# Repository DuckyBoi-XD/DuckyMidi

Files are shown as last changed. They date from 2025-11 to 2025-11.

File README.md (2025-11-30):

# DuckyMidi
The DuckyMidi is a Midi keyboard made from the mini midi magic guide which has a theme of Ducks
Screenshot 2025-11-22 at 9 00 30 PM

## Features

The DuckyMidi has all these features:

- 2 octaves for wide range of sounds
- LCD display for menu display
- 2 rotary knobs for menu/Midi control
- 12 macro keys
- Orpheus Pico microcontroller
- Gateron Pro black switches to feel like a piano key
- Manual on/off switch

## Inspiration

The DuckyMidi was created using the help of the guide from the mini midi magic and was created for many reasons. I'm experienced in music and when I saw the guide for the midi made me intreseted in making a Midi keyboard myself. This was also a great time to revise/practise my PCB designing and CAD modeling.

## Construction
The DuckyMidi is created with a custom PCB and case.

### PCB
The DuckyMidi's PCB:

Screenshot 2025-11-25 at 2 12 49 PM
Screenshot 2025-11-30 at 7 53 48 PM

### Case

The DuckyMidi's Case:

Screenshot 2025-11-30 at 7 02 26 PM
Screenshot 2025-11-30 at 7 53 29 PM
Screenshot 2025-11-30 at 7 04 42 PM

## BOM

| Component | Description | Quantity | Base Cost | Extra Costs | Link |
|---|---|---|---|---|---|
| MCU | Raspberry Pi Pico Board RP2040 | 1 | $3.03 | (*GST*) | https://www.aliexpress.com/item/1005006087823796.html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 |
| Rotary Encoder | Rotary Encoder EC11 w Push Button 5px | 1 | $2.78 | (*GST*) | https://www.aliexpress.com/item/1005005983134515.html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 |
| Rotary Encoder Knob | Aluminum alloy knob cap x2 | 1 | $2.70 | $3.58 +(*GST*)| https://www.aliexpress.com/item/1005006912587864.html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 |
| Switches Piano | Outemu Switch Mechanical Keyboard Switch Black 70 pcs | 1 | $9.19 | (*GST*) | https://www.aliexpress.com/item/1005002378701948.html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 |
| Keycaps White | 10pcs DSA Keycap Set PBT Blank Keycaps 1.5U | 2 | $7.50 | (*GST*) | https://www.aliexpress.com/item/1005009077100804.html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 |
| Keycaps Black | Customized PBT Blank Keycaps DSA 1.25U 10 pcs | 1 | $3.77 | (*GST*) | https://www.aliexpress.com/item/1005006080902747.html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 |
| Keycaps Macro | YMDK MOA Profile 1u Keycaps Dark Blue 25pcs | 1 | $5.77 | (*GST*) | https://www.aliexpress.com/item/1005008795444732.html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,scm-url:1007.40196.439370.0,pvid:3c3f9d66-ba11-4bbf-9a26-8683f9403fb6,tpp_buckets:668%232846%238108%231977&pdp_ext_f=%7B%22order%22%3A%22161%22%2C%22eval%22%3A%221%22%2C%22sceneId%22%3A%2230050%22%2C%22fromPage%22%3A%22recommend%22%7D&pdp_npi=6%40dis%21USD%213.09%212.39%21%21%213.09%212.39%21%402101c44f17631625120246447ec4f0%2112000046697462934%21rec%21NZ%216394433987%21XZ%211%210%21n_tag%3A-29911%3Bd%3A53947009%3Bm03_new_user%3A-29895&utparam-url=scene%3ApcDetailTopMoreOtherSeller%7Cquery_from%3A%7Cx_object_id%3A1005008795444732%7C_p_origin_prod%3A |
| On Off Switch | Push Button Switch 21x15mm SPST 2Pin 6A 250V 5pcs | 1 | $1.97 | (*GST*) | https://www.aliexpress.com/item/1005007945027854.html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 |
| Diodes | 1N4148 DO-35 100pcs | 1 | $2.51 | (*GST*) | https://www.aliexpress.com/item/1005009896621714.html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 |
| Pin Header | Pin Header 2.0MM/2.54MM Pitch Row Female/Male, Single Row 1x40P | 1 | $3.24 | (*GST*) | https://www.aliexpress.com/item/4001122376295.html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 |
| DAC | PCM5100APWR 5pcs | 1 | $2.13 | (*GST*) | https://www.aliexpress.com/item/1005008173380058.html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 |
| LCD/SD Card port | LCD Module Display | 1 | $3.30 | $3.87 +(*GST*)| https://www.aliexpress.com/item/1005003633248802.html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 |
| Jumper Wires | Dupont Line Female To Female | 1 | $2.87 | (*GST*) | https://www.aliexpress.com/item/1005006994502819.html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 |
| Heat insert | Brass Copper Embed Insert Nut 50pc M3 (OD 4.2mm) 4mm | 1 | $2.43 | (*GST*) | https://www.aliexpress.com/item/1005007654176205.html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,scm-url:1007.14452.396806.0,pvid:b34a5f57-fcce-4a45-9604-6228827ab757,tpp_buckets:668%232846%238108%231977&pdp_ext_f=%7B%22order%22%3A%22360%22%2C%22eval%22%3A%221%22%2C%22sceneId%22%3A%2230050%22%2C%22fromPage%22%3A%22recommend%22%7D&pdp_npi=6%40dis%21USD%211.99%211.90%21%21%211.99%211.90%21%402101d9ef17631744175183084e88a2%2112000041671883302%21rec%21NZ%216394433987%21XZ%211%210%21n_tag%3A-29911%3Bd%3A53947009%3Bm03_new_user%3A-29895&utparam-url=scene%3ApcDetailTopMoreOtherSeller%7Cquery_from%3A%7Cx_object_id%3A1005007654176205%7C_p_origin_prod%3A&search_p4p_id=202511141840175552440462087719283089_2 |
| M3 Screw | Stainless Steel Laptop Computer Cross Phillips 50pc M3 14mm | 1 | $3.32 | (*GST*) | https://www.aliexpress.com/item/4001248931159.html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 |
| PCB | JLCPCB PCB | 5 | $32.40 | (*GST*) | N/A |
| **Total** | | | **$96.36** | |

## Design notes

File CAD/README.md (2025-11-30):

### This is the file of the CAD model of the case.

The file called **DuckyMidi Production Case.step** is the file to be printed

The file called **DuckyMidi.step** is the PCB CAD model

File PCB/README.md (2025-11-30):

### This is a PCB files of the project

The production file is the file that I would send to the manufacturer

The rest is just the kicad files

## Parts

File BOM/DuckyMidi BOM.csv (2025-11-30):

Bill of Materials
Components | Description | Base Cost | Extra Costs | Links
MCU | Raspberry Pi Pico Board RP2040 | $3.03 |  | https://www.aliexpress.com/item/1005006087823796.html?curPageLogUid=tcKrQuvSvlbc
Rotary Encoder | Rotary Encoder EC11 w Push Button | $2.78 |  | https://www.aliexpress.com/item/1005005983134515.html?curPageLogUid=zw64DmhjwP3R
Rotary Encoder Knob | Aluminum alloy knob cap | $2.70 | $3.58 | https://www.aliexpress.com/item/1005006912587864.html?curPageLogUid=zdhAQMLQWEjD
Switches Piano | Outemu Switch Mechanical Keyboard Switch Black 70 pcs | $9.19 |  | https://www.aliexpress.com/item/1005002378701948.html?curPageLogUid=p8GAhwpPO6Oo
Keycaps White | 10pcs DSA Keycap Set PBT Blank Keycaps 1.5U x2 | $7.50 |  | https://www.aliexpress.com/item/1005009077100804.html?curPageLogUid=RocAxgbWRvrD
Keycaps Black | Customized PBT Blank Keycaps DSA 1.25U | $3.77 |  | https://www.aliexpress.com/item/1005006080902747.html?curPageLogUid=NbvIijfb90bX
Keycaps Macro | YMDK MOA Profile1u Keycaps Dark Blue | $5.77 |  | https://www.aliexpress.com/item/1005008795444732.html?scm_id=1007.40196.439370.0&scm-url=1007.40196.439370.0
On Off Switch | Push Button Switch 21x15mm SPST 2Pin 6A 250V | $1.97 |  | https://www.aliexpress.com/item/1005007945027854.html?curPageLogUid=Vng3iI0yCpsS
Diodes | 1N4148 DO-35 | $2.51 |  | https://www.aliexpress.com/item/1005009896621714.html?curPageLogUid=uuyJszEGKD0D
Pin Header | Pin Header 2.0MM/2.54MM Pitch Row Female/Male, Single Row 1x40P | $3.24 |  | https://www.aliexpress.com/item/4001122376295.html?curPageLogUid=15XEU1QMwrxO
DAC | PCM5100APWR | $2.13 |  | https://www.aliexpress.com/item/1005008173380058.html?curPageLogUid=G8fdJ97Ygiqn
LCD/SD Card port | LCD Module Display | $3.30 | $3.87 | https://www.aliexpress.com/item/1005003633248802.html?curPageLogUid=4gMrdLkJL4NF
Jumper Wires | Dupont Line Female To Female | $2.87 |  | https://www.aliexpress.com/item/1005006994502819.html?curPageLogUid=zizVsMG2LrFv
Heat insert | Brass Copper Embed Insert Nut 50pc M3 (OD 4.2mm) 4mm | $2.43 |  | https://www.aliexpress.com/item/1005007654176205.html?scm_id=1007.14452.396806.0&scm-url=1007.14452.396806.0
M3 Screw | Stainless Steel Laptop Computer Cross Phillips 50pc M3 14mm | $3.32 |  | https://www.aliexpress.com/item/4001248931159.html?curPageLogUid=KvbKqaCNqWL5
PCB | JLCPCB PCB | $32.40 |  | N/A
Total |  | $96.36

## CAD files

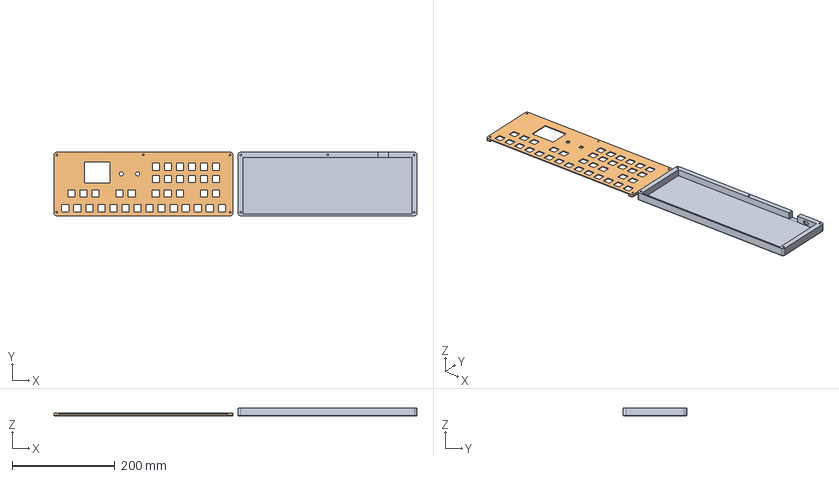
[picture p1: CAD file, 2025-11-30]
CAD/DuckyMidi Production Case.step
708.0 x 124.0 x 16.0 mm

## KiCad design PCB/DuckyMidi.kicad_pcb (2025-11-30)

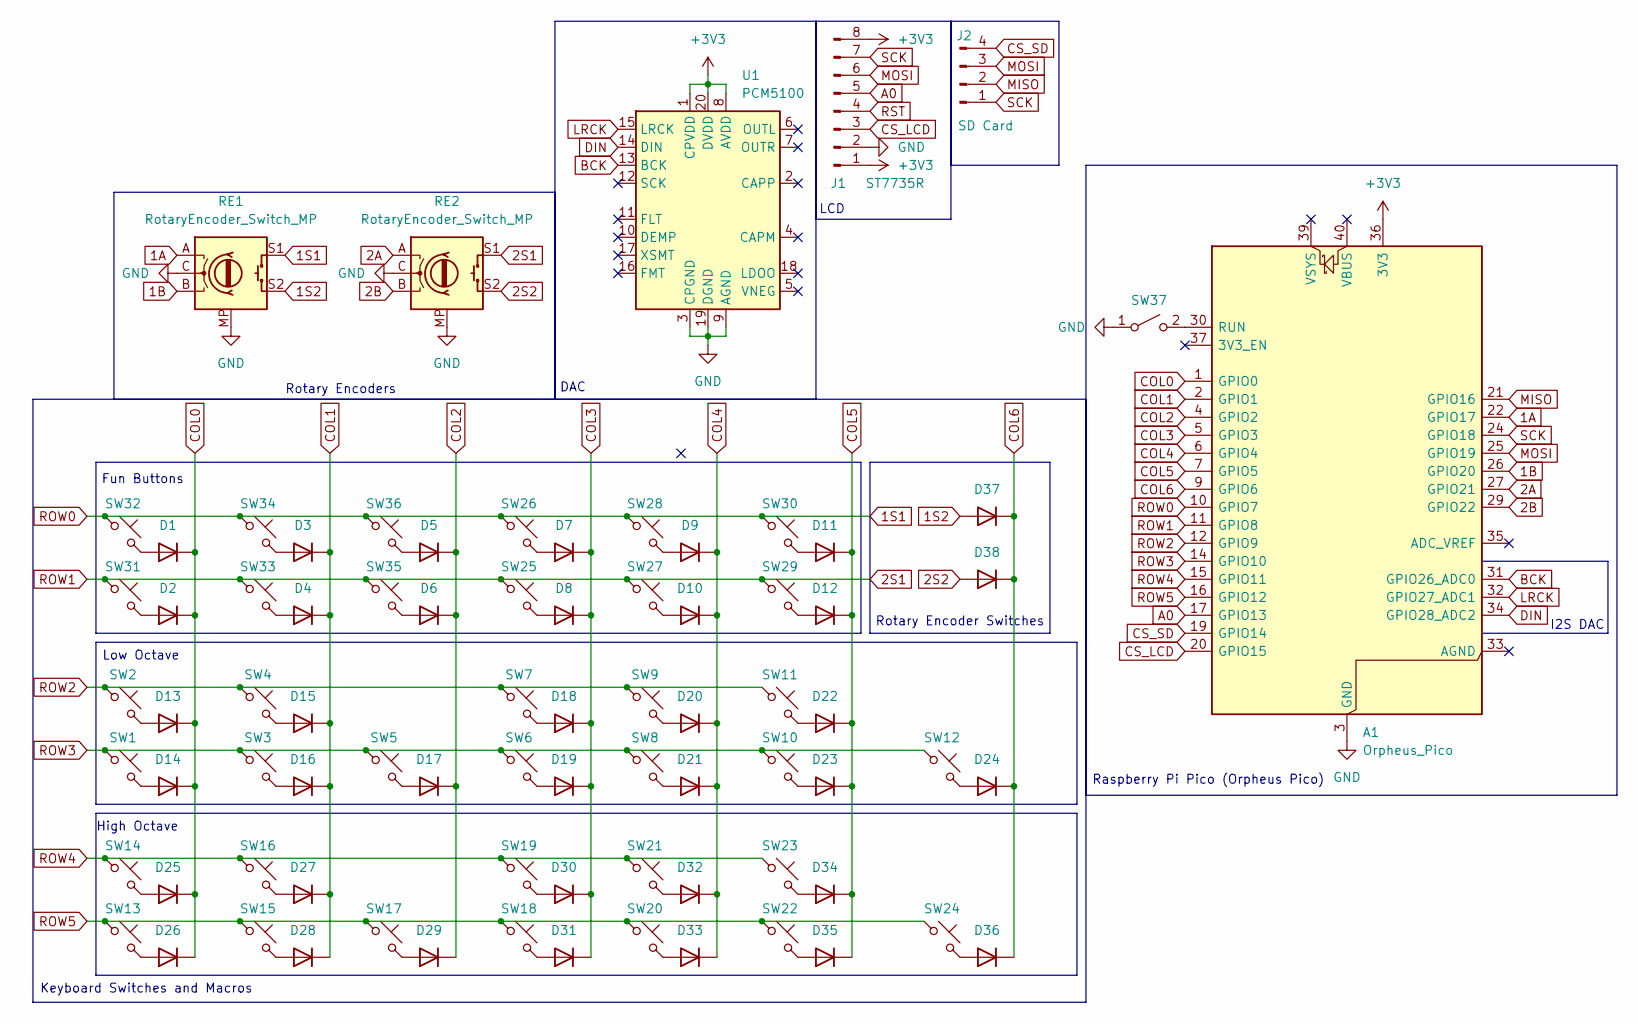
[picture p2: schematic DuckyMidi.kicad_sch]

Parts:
A1: Orpheus_Pico; RaspberryPi_Pico_Common_Unspecified
D1, D2, D3, D4, D5, D6, D7, D8, D9, D10, D11, D12, D13, D14, D15, D16, D17, D18, D19, D20, D21, D22, D23, D24, D25, D26, D27, D28, D29, D30, D31, D32, D33, D34, D35, D36, D37, D38: 1N4148; D_DO-35_SOD27_P7.62mm_Horizontal
J1: ST7735R; PinHeader_1x08_P2.54mm_Vertical
J2: SD Card; PinHeader_1x04_P2.54mm_Vertical
RE1, RE2: RotaryEncoder_Switch_MP; RotaryEncoder_Alps_EC11E-Switch_Vertical_H20mm_MountingHoles
SW1, SW2, SW3, SW4, SW5, SW6, SW7, SW8, SW9, SW10, SW11, SW12, SW13, SW14, SW15, SW16, SW17, SW18, SW19, SW20, SW21, SW22, SW23, SW24, SW25, SW26, SW27, SW28, SW29, SW30, SW31, SW32, SW33, SW34, SW35, SW36: SW_Push_45deg; MX_PCB_1.00u
SW37: SW_SPST; PinHeader_1x02_P2.54mm_Vertical
U1: PCM5100; TSSOP-20_4.4x6.5mm_P0.65mm

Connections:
1A: A1.22 (GPIO17), RE1.A
1B: A1.26 (GPIO20), RE1.B
1S1: A1.10 (GPIO7), RE1.S1, SW26.1, SW28.1, SW30.1, SW32.1, SW34.1, SW36.1
1S2: D37.2 (A), RE1.S2
2A: A1.27 (GPIO21), RE2.A
2B: A1.29 (GPIO22), RE2.B
2S1: A1.11 (GPIO8), RE2.S1, SW25.1, SW27.1, SW29.1, SW31.1, SW33.1, SW35.1
2S2: D38.2 (A), RE2.S2
+3V3: A1.36 (3V3), J1.1, J1.8, U1.1 (CPVDD), U1.8 (AVDD), U1.20 (DVDD)
A0: A1.17 (GPIO13), J1.5
BCK: A1.31 (GPIO26_ADC0), U1.13 (BCK)
COL0: A1.1 (GPIO0), D1.1 (K), D2.1 (K), D13.1 (K), D14.1 (K), D25.1 (K), D26.1 (K)
COL1: A1.2 (GPIO1), D3.1 (K), D4.1 (K), D15.1 (K), D16.1 (K), D27.1 (K), D28.1 (K)
COL2: A1.4 (GPIO2), D5.1 (K), D6.1 (K), D17.1 (K), D29.1 (K)
COL3: A1.5 (GPIO3), D7.1 (K), D8.1 (K), D18.1 (K), D19.1 (K), D30.1 (K), D31.1 (K)
COL4: A1.6 (GPIO4), D9.1 (K), D10.1 (K), D20.1 (K), D21.1 (K), D32.1 (K), D33.1 (K)
COL5: A1.7 (GPIO5), D11.1 (K), D12.1 (K), D22.1 (K), D23.1 (K), D34.1 (K), D35.1 (K)
COL6: A1.9 (GPIO6), D24.1 (K), D36.1 (K), D37.1 (K), D38.1 (K)
CS_LCD: A1.20 (GPIO15), J1.3
CS_SD: A1.19 (GPIO14), J2.4
DIN: A1.34 (GPIO28_ADC2), U1.14 (DIN)
GND: A1.3 (GND), A1.8 (GND), A1.13 (GND), A1.18 (GND), A1.23 (GND), A1.28 (GND), A1.38 (GND), J1.2, RE1.C, RE1.MP, RE2.C, RE2.MP, SW37.1 (A), U1.3 (CPGND), U1.9 (AGND), U1.19 (DGND)
LRCK: A1.32 (GPIO27_ADC1), U1.15 (LRCK)
MISO: A1.21 (GPIO16), J2.2
MOSI: A1.25 (GPIO19), J1.6, J2.3
unnamed: A1.30 (RUN), SW37.2 (B)
unnamed: D1.2 (A), SW32.2
unnamed: D2.2 (A), SW31.2
unnamed: D3.2 (A), SW34.2
unnamed: D4.2 (A), SW33.2
unnamed: D5.2 (A), SW36.2
unnamed: D6.2 (A), SW35.2
unnamed: D7.2 (A), SW26.2
unnamed: D8.2 (A), SW25.2
unnamed: D9.2 (A), SW28.2
unnamed: D10.2 (A), SW27.2
unnamed: D11.2 (A), SW30.2
unnamed: D12.2 (A), SW29.2
unnamed: D13.2 (A), SW2.2
unnamed: D14.2 (A), SW1.2
unnamed: D15.2 (A), SW4.2
unnamed: D16.2 (A), SW3.2
unnamed: D17.2 (A), SW5.2
unnamed: D18.2 (A), SW7.2
unnamed: D19.2 (A), SW6.2
unnamed: D20.2 (A), SW9.2
unnamed: D21.2 (A), SW8.2
unnamed: D22.2 (A), SW11.2
unnamed: D23.2 (A), SW10.2
unnamed: D24.2 (A), SW12.2
unnamed: D25.2 (A), SW14.2
unnamed: D26.2 (A), SW13.2
unnamed: D27.2 (A), SW16.2
unnamed: D28.2 (A), SW15.2
unnamed: D29.2 (A), SW17.2
unnamed: D30.2 (A), SW19.2
unnamed: D31.2 (A), SW18.2
unnamed: D32.2 (A), SW21.2
unnamed: D33.2 (A), SW20.2
unnamed: D34.2 (A), SW23.2
unnamed: D35.2 (A), SW22.2
unnamed: D36.2 (A), SW24.2
ROW2: A1.12 (GPIO9), SW2.1, SW4.1, SW7.1, SW9.1, SW11.1
ROW3: A1.14 (GPIO10), SW1.1, SW3.1, SW5.1, SW6.1, SW8.1, SW10.1, SW12.1
ROW4: A1.15 (GPIO11), SW14.1, SW16.1, SW19.1, SW21.1, SW23.1
ROW5: A1.16 (GPIO12), SW13.1, SW15.1, SW17.1, SW18.1, SW20.1, SW22.1, SW24.1
RST: J1.4
SCK: A1.24 (GPIO18), J1.7, J2.1

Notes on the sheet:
DAC
Rotary Encoders
Low Octave
High Octave
Rotary Encoder Switches
I2S DAC
LCD
Raspberry Pi Pico (Orpheus Pico)
Fun Buttons
Keyboard Switches and Macros

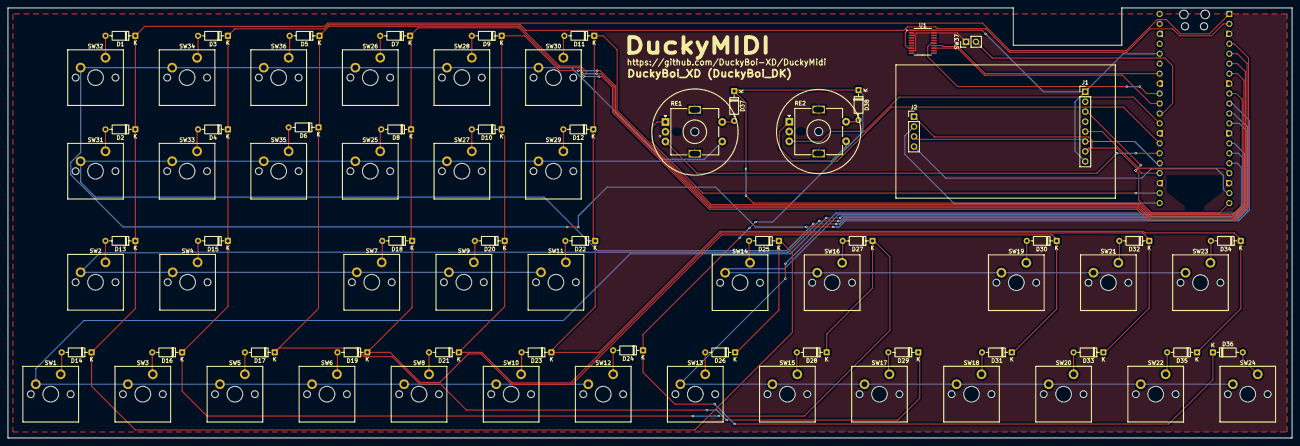
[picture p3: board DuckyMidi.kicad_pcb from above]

Board: 2 copper layers, 327.7 x 109.7 mm, 81 parts (1 on the bottom side), 67 nets.

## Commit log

2025-11-14 Added Nov 14 - Schematics work
    Document project details and initial progress on the DuckyMidi MIDI keyboard.
2025-11-15 Add entry for November 15th PCB editor
    Documented progress on PCB design and component placement.
2025-11-30 Add README for CAD model files
2025-11-30 Update README to remove unnecessary information
    Removed redundant line about CAD model file.
2025-11-30 Create README.md for PCB project files
    Add README to explain PCB files and production process
2025-11-30 Add README for Bill Of Materials
2025-11-30 Add BOM section with component details
    Added a Bill of Materials (BOM) section with component details.
2025-11-30 Added BOM to READEME.md
2025-11-30 Add GST details to BOM components
    Added GST information to various components in the BOM.
2025-11-30 Add PCB CAD model information to README
2025-11-30 Revise component list and update PCB pricing
    Updated the components list and their prices in the README file, including a change in the quantity and price of the PCB.
